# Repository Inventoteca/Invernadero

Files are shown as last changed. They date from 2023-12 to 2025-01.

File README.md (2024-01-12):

# Invernadero
Maqueta de invernadero automatizado.  

Hardware:  
- Módulo ESP32
- Pantalla LCD con controlador ILI9341
- Panel touch resistivo con controlador XPT2046
- Ventiladores 91mm x 91mm 12V
- Puente H DRV8833
- Sensor de temperatura y humedad DHT22
- Bomba de agua peristáltica
- Módulo de 2 relevadores de 5V
- Atomizador de agua piezoeléctrico
- Sensor de humedad de suelo HW-080
- Iluminación con LEDs RGB 12V
- Fuente de alimentación de 12V

En la carpeta "codigo" están los programas escritos en el IDE de Arduino.  
En la carpeta "diagramas" están los diagramas de conexiones creados con Fritzing.  
En la carpeta "dibujo" hay bocetos de la interfaz gráfica.  

Los programas utilizan diversas librerías para cada sensor y actuador.  

Cambiar configuración para que los warnings no sean tratados como errores  
https://forum.arduino.cc/t/esp32-unused-variable-compile-error/1039022/15  

## Pantalla
2.4 pulgadas, resolución 320x240, interfaz SPI, controlador ILI9341.  
http://www.lcdwiki.com/2.4inch_SPI_Module_ILI9341_SKU:MSP2402  

Librería **TFT_eSPI**.
Permite mostrar gráficos de diferentes tipos y también implementa la lectura del panel touch.  
https://github.com/Bodmer/TFT_eSPI  
(tutorial 1: https://electropeak.com/learn/interfacing-2-8-inch-tft-lcd-touch-screen-with-esp32)  
No tine documentación oficial, pero esta sirve  
https://github.com/Ambercroft/TFT_eSPI/wiki  

Se puede usar junto a la librería **tft_eWidget** que define algunos 
elementos para interfaces gráficas, pero no son muy bonitos  
https://github.com/Bodmer/TFT_eWidget  

Librería que se probó anteriormente **Adafruit_ILI9341**  
https://github.com/adafruit/Adafruit_ILI9341  
Esa libreria depende de **Adafruit_GFX** que permite dibujar primitivas gráficas y texto  
https://learn.adafruit.com/adafruit-gfx-graphics-library/graphics-primitives  
Utiliza el hardware SPI. También se puede usar software SPI y elegir los pines, pero la comunicación resulta más lenta.  

## Touch
La pantalla tiene integrado un panel touch resistivo con controlador XPT2046.  

La librería **tft_eSPI** incluye funciones para usar el panel touch.  

Otra librería **XPT2046_Touchscreen**  
https://github.com/PaulStoffregen/XPT2046_Touchscreen  
Esta librería devuelve valores de coordenadas de 0 a 4096 (en en teoría).
No está calibrada a la resolución de la pantalla.
Para convertir las lecturas a coordenadas de la pantalla, se puede usar la función map().  
Usa hardware SPI, el mismo que la pantalla, de esa forma se reutilizan 3 pines del ESP32 (MISO, MOSI, CLK).  
(tutorial 1: https://bytesnbits.co.uk/spi-lcd-setup-arduino/ juego de bloques, cómo se descarga el código?)  
(ejemplo donde se configuran los pines SPI https://www.esp32.com/viewtopic.php?t=3746 
https://gist.github.com/CelliesProjects/99a56121e7c8a7cb00d5b46270e74b75)  
En esta discusión sugieren comprobar el valor de presión para no 
detectar falsos clics si se usa la librería **XPT2046_Touchscreen**  
https://forum.arduino.cc/t/problem-with-il9341-and-xpt2046-phantom-touch/688062  

Este es un fork de la librería aterior, que agrega código para calibración. No se ha probado.  
https://github.com/ardnew/XPT2046_Calibrated  

La librería **URTouch** funcionó correctaente con Arduino Mega, pero no es compatible con ESP32  
http://www.rinkydinkelectronics.com/library.php?id=92  

## Interfaz gráfica
La interfaz gráfica (GUI) se puede crear con diferentes librerías a través de código o de un editor gráfico.  

Una librería es **GUIslice** que tiene un editor gráfico **Gluislice Builder**, 
pero es un poco difícil de usar y los elementos no son bonitos.  

**LVGL** parece una mejor opción, pero aprender a usarla llevará tiempo  
https://daumemo.com/lcd-gui-with-lvgl-with-esp-32-diy-generator-part-15/  

**ESPHome** parece interesante, pero también llevará tiempo aprender a usarla  
https://esphome.io  

Se puede usar **displayio** con **CircuitPyhon**, pero implica volver a programar todo  
https://learn.adafruit.com/circuitpython-display-support-using-displayio  

Colo picker 565  
https://rgbcolorpicker.com/565  

Varios iconos se pueden obtener de estas páginas  
https://klarsys.github.io/angular-material-icons/  
https://fontawesome.com/v4/icons/  
https://github.com/Paul-Reed/weather-icons-lite/blob/master/css_mappings.md  
https://fonts.google.com/icons  

## Ventiladores
Los ventiladores se conectan a un módulo DRV8833 (puente H) y se controlan 
con 2 pines que envían señales PWM para poder regular la velocidad.  
Cada ventilador puede ser controlado con 2 pines, pero solo se usará 1 pin, ya que no es necesario invertir la dirección de giro.  
https://forum.arduino.cc/t/troubleshooting-voltage-drop-to-motors/1135652  
https://circuitdigest.com/microcontroller-projects/interface-drv8833-dual-motor-driver-module-with-arduino  

## Bomba de agua
Se activa con un relevador que es controlado por 1 pin digital.
Se usa un relevador porque no se necesita regular la velocidad.  

## Atomizador
Usa un elemento piezoeléctrico que vibra y expulsa el agua en forma de gotas muy pequeñas. 
No se puede usar pwm directo del microcontrolador al piezoeléctrico porque funciona con voltaje alto.
Se puede conectar un relevador o solo optoacoplador al botón que activa el funcionamiento.  

## Sensor de temperatura y humedad
Sensor DHT22. Solo usa 1 pin de comunicación.  
Librería **DHT sensor library** by Adafruit.  

## Sensor de humedad de suelo
Tiene dos salidas: una digital y una analógica
Dependiendo de la lectura obtenida, se activa o desactiva la bomba de agua.  
Se usará la salida analógica.  
https://www.electronicwings.com/esp32/soil-moisture-sensor-interfacing-with-esp32  

## LEDs
Iluminación con LEDs RGB. Funcionan con 12V. Se controlan con MOSFETs y PWM.  
https://learn.adafruit.com/rgb-led-strips/usage  

## Reloj (opcional)
Módulo RTC para realizar ciclos que dependen de la hora.

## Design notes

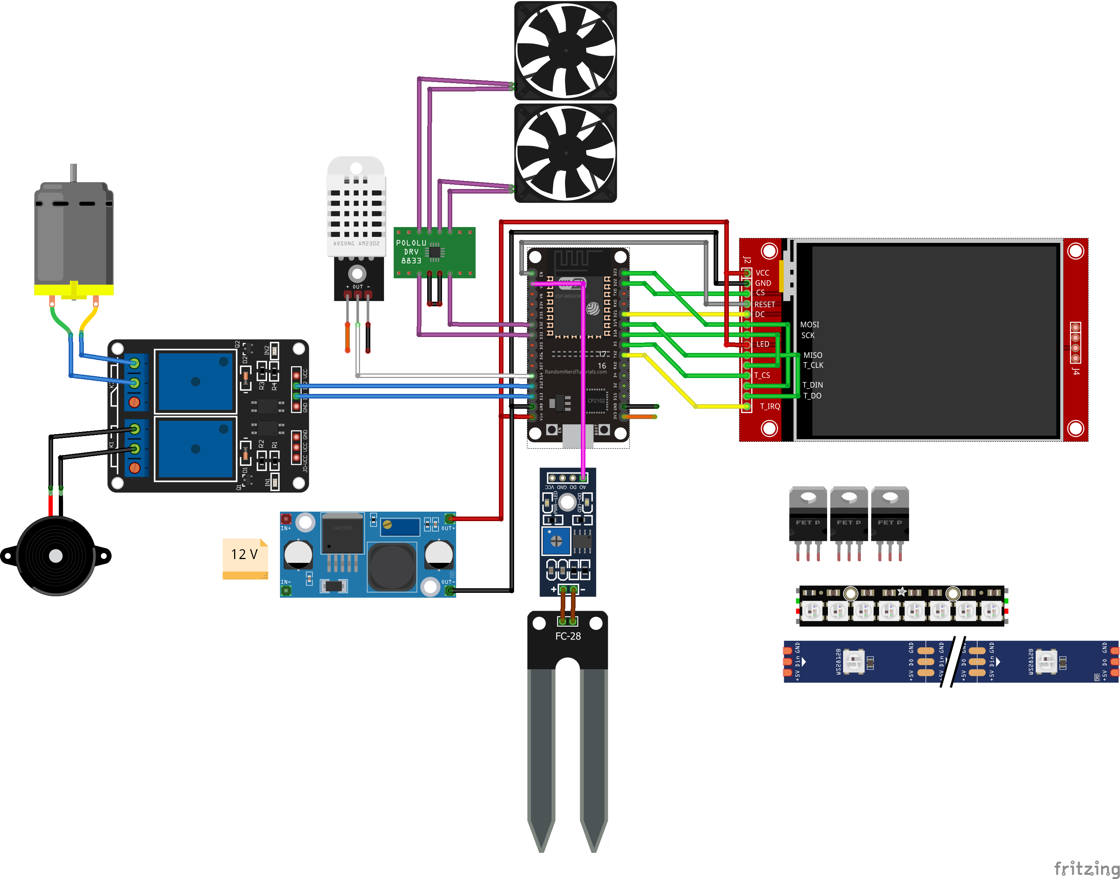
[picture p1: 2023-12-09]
diagrama/diagrama invernadero r2.png

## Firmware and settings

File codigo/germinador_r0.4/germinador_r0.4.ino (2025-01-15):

/*
  GERMINADOR
  Maqueta de invernadero automatizado.
  El código inicial está basado en
  - ejemplo "Keypad_240x320" de la librería TFT_eSPI
  - ejemplo dht22

  En este archivo se encuentra la lógica principal del programa

  Versiones
  0.3 agrega varias pantallas con controles deslizantes
  0.4 cambiar pines y agregar medidor de PH PH
*/

//===================================================================
// Definir pines
#define PIN_SUELOD 35  //sensor de humedad del suelo (lectura digital)
#define PIN_SUELOA 34  //sensor de humedad del suelo (lectura analogica)
#define PIN_PHD 39     //sensor de PH (lectura digital)
#define PIN_PHA 36     //sensor de PH (lectura analogica)
#define PIN_VENT1 32   //ventilador 1 (PWM)
#define PIN_VENT2 33   //ventilador 2 (PMW)
#define PIN_R 12       //LED R (PMW)
#define PIN_G 13       //LED G (PMW)
#define PIN_B 14       //LED B (PMW)
#define PIN_BOMBA 26   //relevador para bomba de agua
#define PIN_SPRAY 25   //relevador para bomba de atomizador/spray
#define PIN_BEEP 17    //buzzer piezoeléctrico

// Los pines para la pantalla y el panel touch se definen en "Setup21_ILI9488.h"

// nuevos pines agregados
//#define PIN_BSPRAY 13  //bomba para el spray
//#define PIN_SSPRAY 39  //36//sensor de agua para el spray
// cada vez que se presiona un botón suena el beep

// sensor de temperatura y humedad
#define PIN_DHT 27
#include "DHT_Async.h"
DHT_Async dht(PIN_DHT, DHT_TYPE_22);
//#include <dhtESP32-rmt.h>
float humedad, temperatura;  //variables para guardar lecturas del sensor
// las lecturas se realizan cada 2 segundos
#define DHT_PERIOD 3000  //4000//periodo de lectura en milisegundos
unsigned long dht_now;   //marca de tiempo en la que se hizo una lectura

// Variables para guardar el estado de los sensores y actuadores
bool suelod;  //guarda un estado alto o bajo
//es alto cuando la resistencia es alta?
int sueloa;  //guarda la lectura analógia (12 bits --> 0 a 4095)
//es el valor de la resistencia de la tierra
//cuando la resistencia es infinita la lectura es 4095
//cuando la resistencia es cero la lectura es 0
//el nivel de humedad como porcentaje se puede calcular así:
//int humedad_suelo = ((4095 - sueloa) * 100) / 4095;
int humedad_suelo = (4095 - sueloa) / 41;  // forma más simple
//se debe cambiar el tipo de variable?
//cuando la humedad baja de un nivel determinado, se enciende la bomba
int lim_humedad_suelo = 50;  //limite de humedad del suelo
//si la humedad baja de ese nivel, se activa la bomba, si se pasa de ese nivel, apaga la bomba
//la lectura de este sensor se realiza con un poco de retardo
#define SH_PERIOD 1000  //sensor humedad periodo
unsigned long sh_now;   //sensor humedad marca temporal

//el estado de los ventiladores se guarda en las siguientes variables
//se usará pwm con resolución de 8 bits (0 a 255)
//pero se usan otras variables que guardan un valor de 0 a 10
//uint8_t vent1 = 0;
//uint8_t vent2 = 0;
float vent1 = 0;
float vent2 = 0;
uint8_t pwm_vent1 = 0;
uint8_t pwm_vent2 = 0;
//el ciclo de trabajo asigna con analogWrite,
//sin embargo la frecuencia del pwm se escucha como zumbido
//para cambiar a una frecuencia no audible se puede usar la librería ledc
//(https://lastminuteengineers.com/esp32-pwm-tutorial/)
//(https://randomnerdtutorials.com/esp32-pwm-arduino-ide/)
//los ventiladores se activan cuando la temperatura ambiente sobrepasa un valor
//uint8_t lim_temperatura = 20; //en grados celcius

int lim_temperatura = 20;  //en grados celcius
//la lectura del sensor es float, se debe usar el mismo tipo de variable?

//para asignar este limite se puede usar una barra deslizadora de 10 a 50 grados
//cuál es el rango ideal?
//los ventiladores pueden encender con una velocidad proporcional a la temperatura
//o pueden encender a una velodiad predeterminada (se encenderán a la máxima velocidad, es más fácil)
//con el control manual se pueden activar los ventiladores de manera independiente,
//pero con el control automático los dos ventiladores se encienden o apagan al mismo tiempo

//los leds usan pwm como los ventiladores (analogWrite)
//es necesario cambiar la resolución o frecuencia de pwm para los leds?
uint8_t pwm_r = 0;
uint8_t pwm_g = 0;
uint8_t pwm_b = 0;
//qué condición hace que los leds enciendan?
//puede ser un temporizador que active la luz por periodos
//por ahora solo controlarán de forma manual
//estos son los valores por defatul al encender cuando el control sea atuomático
uint8_t def_r = 255;
uint8_t def_g = 255;
uint8_t def_b = 255;
//
float val_r = 0;
float val_g = 0;
float val_b = 0;

//la bomba de agua se activa con un relevador. Tiene lógica invertida:
//cuando el pin está en HIGH, la bomba se apaga
//cuando el pin está en LOW, la bomba se enciende
bool bomba = false;  //estado de la boma, el pin se escribirá invertido

//el nebulizador/atomizador/spray también se activa con un relevador
bool spray = false;  //estado del spray
//se necesitaba un pulso, pero ya no
//pero necesita un pulso (flanco descendente) para activarse y otro pulso para desactivarse
//qué duración debe tener ese pulso?
//#define T_PULSO_SPRAY 30  //milisegundos
//el relevador se activa un momento y luego se desactiva

#define T_PULSO_BEEP 30  //milisegundos, duracion minima del beep

int lim_humedad = 60;  //si baja de este valor, se activa el nebulizador
//float lim_humedad = 60; //usar float?

//puede existir un control para seleccionar funcionamiento manual o automático
//por ahora se cambiará a manual si se cambian los valores de los actuadores
//y regresará a automático si se cambian los valores de los límites
bool vent_auto = true;   //ventilador automático (se activa con la temperatura)
bool spray_auto = true;  //nebulizador/spray automático (se activa con la humedad)
bool bomba_auto = true;  //bamba automática (se activa con la humedad del suelo)
/*
  ¿Qué pasa si el usuario utiliza el control manual?
  Lo más fácil es sobre-escribir el valor al instante
  y cuando vuelve a leer el sensor retoma el valor por default.
  La segunda opción es que cuando el usuario usa el control manual
  se activa un temporizador que mantiene los valores por un minuto
  y luego regresa a su valor por default
  También se puede reactivar el control automático si se reasigna el valor límite
*/

// Código para el display
#include "display.h"

// Código para el access point y página web
#include "server.h"

//------------------------------------------------------------------------------------------
void setup() {
  // configurar entradas y salidas
  pinMode(PIN_SUELOD, INPUT);
  pinMode(PIN_SUELOA, INPUT);
  pinMode(PIN_VENT1, OUTPUT);
  pinMode(PIN_VENT2, OUTPUT);
  pinMode(PIN_R, OUTPUT);
  pinMode(PIN_G, OUTPUT);
  pinMode(PIN_B, OUTPUT);
  pinMode(PIN_BOMBA, OUTPUT);
  pinMode(PIN_SPRAY, OUTPUT);  //controlar spray
  //pinMode(PIN_BSPRAY, OUTPUT);  //bomba spray
  //pinMode(PIN_SSPRAY, INPUT);   //sensor spray
  pinMode(PIN_BEEP, OUTPUT);  //buzzer piezoeléctrico
  //
  analogRead(PIN_SUELOA);  //descartar primera lectura
  analogRead(PIN_PHA);     //descartar primera lectura
  analogWrite(PIN_VENT1, 0);
  analogWrite(PIN_VENT2, 0);
  analogWrite(PIN_R, 0);  //si el pin es DAC no saca PWM?
  analogWrite(PIN_G, 0);
  analogWrite(PIN_B, 0);
  digitalWrite(PIN_BOMBA, HIGH);  //relevador apagado en HIGH
  //digitalWrite(PIN_BSPRAY, HIGH);  //relevador apagado en HIGH
  digitalWrite(PIN_SPRAY, HIGH);  //relevador apagado en HIGH
  digitalWrite(PIN_BEEP, HIGH);
  digitalWrite(PIN_BEEP, LOW);
  //
  //dht.begin();
  //uint8_t dht_error = read_dht(temperatura, humedad, PIN_DHT, DHT22); //descartar primera lectura
  dht.measure(&temperatura, &humedad);  //descartar primera lectura
  dht.measure(&temperatura, &humedad);
  dht_now = millis();  //guardar marca temporal
  digitalWrite(PIN_BEEP, LOW);

  // Use serial port
  Serial.begin(115200);
  Serial.print("\nGERMINADOR\n");
  digitalWrite(PIN_BEEP, LOW);

  // Initialise the TFT screen
  tft.init();
  tft.setRotation(1);  //3 // Set the rotation before we calibrate
  touch_calibrate();   // Calibrate and retrieve the scaling factors
  //tft.fillScreen(TFT_BLACK); // Clear the screen
  digitalWrite(PIN_BEEP, LOW);

  // Mensaje de bienvenida
  tft.fillScreen(FONDO);
  tft.setTextFont(4);
  tft.setTextSize(1);
  tft.setTextColor(TFT_WHITE);
  tft.setTextDatum(TC_DATUM);  //top-centre
  tft.drawString("GERMINADOR PARA ZONAS URBANAS", 160, 80);
  tft.drawString("CONTROLADO MEDIANTE TECNOLOGIA IoT", 160, 110);

  // Iniciar server
  serverSetup();
  delay(2000);  //esperar para que se vea el mensaje de bienvenida

  //Inicializar controles de todas las pantallas/páginas
  setupUI0();  //principal
  setupUI1();  //temperatura
  setupUI2();  //humedad
  setupUI3();  //humedad suelo
  setupUI4();  //ventiladores
  setupUI5();  //color
  setupUI6();  //conectar
  drawUI0();   //Dibujar interfaz principal
  //drawUI1();
  //while (true) {}
}

//------------------------------------------------------------------------------------------
void loop(void) {
  // Leer sensor dht de manera periódica =================================
  if ((unsigned long)(millis() - dht_now) > DHT_PERIOD) {
    dht_now = millis();
    dht.measure(&temperatura, &humedad);

    //imprimir en consola
    /*
    Serial.print("T: ");
    Serial.print(temperatura, 1);
    Serial.print("  H: ");
    Serial.print(humedad, 1);
    Serial.println("%");
    */

    //actualizar pantalla principal
    if (pantalla == 0) {
      tft.setTextFont(4);
      tft.setTextSize(1);
      tft.setTextColor(TFT_WHITE, TFT_BLACK);
      String t = String(temperatura, 0) + " `C  ";
      String h = String(humedad, 0) + "%   ";
      tft.drawString(t, btx0[0], bty0[0]);
      tft.drawString(h, btx0[1], bty0[1]);
    }

    //si está activado el control automático del ventilador
    if (vent_auto) {
      //si la temperatura sobrepasa el límite
      if (temperatura > lim_temperatura) {
        vent1 = 10;  //encender a la máxima velocidad
        vent2 = 10;
        analogWrite(PIN_VENT1, vent1 * 25.5);
        analogWrite(PIN_VENT2, vent2 * 25.5);
        Serial.println("Vent ON (auto)");
      }
      //si la temperatura está debajo del límite
      else if (temperatura < lim_temperatura) {
        vent1 = 0;  //apagar ventiladores
        vent2 = 0;
        analogWrite(PIN_VENT1, vent1 * 25.5);
        analogWrite(PIN_VENT2, vent2 * 25.5);
        Serial.println("Vent OFF (auto)");
      }
    }  //fin if vent_auto

    //si está activado el control automático del nebulizador/spray
    if (spray_auto) {
      //si la humedad es más baja que el límite
      if (humedad < lim_humedad) {
        //encender el spray solo si está apagado
        if (spray == false) {
          digitalWrite(PIN_SPRAY, LOW);  //recuerda, el relevador se activa en bajo
          //delay(T_PULSO_SPRAY);           //tiempo que tarda el pulso
          //digitalWrite(PIN_SPRAY, LOW);   //desactivar relevador
          spray = true;                   //guardar estado actual
          Serial.println("Spray ON (auto)");
          if (pantalla == 0) tft.drawXBitmap(bix0[5], biy0[5], bi0[5], 32, 32, TFT_CYAN);
        }
      }
      // si la humedad está arriba del límite
      else if (humedad > lim_humedad) {
        //apagar el nebulizador spray, solo si está encendido
        if (spray == true) {
          digitalWrite(PIN_SPRAY, HIGH);  //recuerda, el relevador se activa en bajo
          //delay(T_PULSO_SPRAY);           //tiempo que tarda el pulso
          //digitalWrite(PIN_SPRAY, LOW);   //desactivar relevador
          spray = false;                  //guardar estado actual
          Serial.println("Spray OFF (auto)");
          if (pantalla == 0) tft.drawXBitmap(bix0[5], biy0[5], bi0[5], 32, 32, 0);
        }
      }
    }  //fin if spray_auto
  }    //fin DHT_PERIOD

  // El sensor de humedad de suelo se lee más seguido ===============================
  // XXXXXXXXXXXXX También se lee el sensor de agua dentro para el spray XXXXXXXXXX
  if ((unsigned long)(millis() - sh_now) > SH_PERIOD) {
    sh_now = millis();
    suelod = digitalRead(PIN_SUELOD);      //lectura digital
    sueloa = analogRead(PIN_SUELOA);       //lectura analógica
    humedad_suelo = (4095 - sueloa) / 41;  //calcular porcentaje de humedad
    //
    //sensor de agua para el spray
    // 0 significa nivel alto, 1 significa nivel bajo
    // activar o desactivar la bomba
    //digitalWrite(PIN_BSPRAY, !digitalRead(PIN_SSPRAY));
    /*
    Serial.print("HS: ");
    Serial.print(humedad_suelo);
    Serial.println("%");
    */

    // Actualizar pantalla 0 (principal)
    if (pantalla == 0) {
      tft.setTextFont(4);
      tft.setTextSize(1);
      tft.setTextColor(TFT_WHITE, TFT_BLACK);
      String hs = String(humedad_suelo) + "%   ";
      tft.drawString(hs, btx0[2], bty0[2]);
    }

    //si el control automático de la bomba está activado
    if (bomba_auto) {
      //si la humedad del suelo está debajo del límite
      if (humedad_suelo < lim_humedad_suelo) {
        digitalWrite(PIN_BOMBA, LOW);  //encendido en nivel bajo
        bomba = true;                  //guardar estado actual
        Serial.println("Bomba ON (auto)");
        //dibujar icono
        if (pantalla == 0) tft.drawXBitmap(bix0[6], biy0[6], bi0[6], 32, 32, TFT_CYAN);
      }
      //en cambio, si la humedad del suelo está arriba del límite
      if (humedad_suelo > lim_humedad_suelo) {
        digitalWrite(PIN_BOMBA, HIGH);  //apagado en nivel alto
        bomba = false;                  //guardar estado actual
        Serial.println("Bomba OFF (auto)");
        //dibujar icono
        if (pantalla == 0) tft.drawXBitmap(bix0[6], biy0[6], bi0[6], 32, 32, 0);
      }
    }
  }

  //Detectar clics en la pantalla ============================================
  if ((unsigned long)(millis() - touch_now) > TOUCH_PERIOD) {
    touch_now = millis();

    //realizar acciones de la pantalla conrrespondiente
    switch (pantalla) {
      case 0:
        loopUI0();
        break;
      case 1:
        loopUI1();
        break;
      case 2:
        loopUI2();
        break;
      case 3:
        loopUI3();
        break;
      case 4:
        loopUI4();
        break;
      case 5:
        loopUI5();
        break;
      case 6:
        loopUI6();
        break;
    }
  }  //fin TOUCH_PERIOD

  // Actualizar server ===================================================
  serverLoop();

}  //fin loop()
//Fin del programa

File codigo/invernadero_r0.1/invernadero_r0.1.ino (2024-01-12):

/*
  INVERNADERO
  Maqueta de invernadero automatizado.
  El código inicial está basado en el ejemplo "Keypad_240x320" de la librería TFT_eSPI.
  Se utiliza la clase "button".
*/

// The SPIFFS (FLASH filing system) is used
// to hold touch screen calibration data
#include "FS.h"

// Iconos
#include "icons/th32.h" //thermometer
#include "icons/drop32.h" //water drop
#include "icons/grass32.h" //grass
#include "icons/fan32.h" //fan
#include "icons/lamp32.h" //lamp
#include "icons/sprink32.h" //sprinkler
#include "icons/pump32.h" //water pump

// Colores
#define FONDO 0x1084
#define PANEL 0x526d
#define GRIS70 0x4a69
#define ICON TFT_CYAN

#include <SPI.h>
#include <TFT_eSPI.h>      // Hardware-specific library
TFT_eSPI tft = TFT_eSPI(); // objeto para manejar la pantalla

// This is the file name used to store the calibration data
// You can change this to create new calibration files.
// The SPIFFS file name must start with "/".
#define CALIBRATION_FILE "/TouchCalData1"

// Set REPEAT_CAL to true instead of false to run calibration
// again, otherwise it will only be done once.
// Repeat calibration if you change the screen rotation.
#define REPEAT_CAL true
// en lugar de usar este define se usará un botón para iniciar la calibración

// Botones de la pantalla principal
TFT_eSPI_Button b[8]; //objetos botón
const int bx[8] = { 20,  20,  20, 180, 250, 180, 250, 180}; //x top-left corner
const int by[8] = { 20,  90, 160,  20,  20,  90,  90, 160}; //y top-left corner
const int bw[8] = {140, 140, 140,  60,  60,  60,  60, 130}; //wdith
const int bh[8] = { 60,  60,  60,  60,  60,  60,  60,  60}; //height
char* bl[8] = {"", "", "", "", "", "", "", "CONECTAR"}; //labels
const uint16_t bc[8] {0, 0, 0, PANEL, PANEL, PANEL, PANEL, PANEL}; //colors
const uint8_t* bi[8] = { //icons
  th32_bits, drop32_bits, grass32_bits,
  fan32_bits, lamp32_bits, sprink32_bits, pump32_bits, 0
};
const int bix[8] = { //icon x top-left corner
  40 - 16, 40 - 16, 40 - 16, 210 - 16, 280 - 16, 210 - 16, 280 - 16, 0
};
const int biy[8] = { //icon y top-left corner
  50 - 16, 120 - 16, 190 - 16, 50 - 16, 50 - 16, 120 - 16, 120 - 16, 0
};

//===================================================================
// Definir pines
// Los pines para la pantalla y el panel touch se definen en "Setup42_ILI9341_ESP32.h"
#define PIN_SUELOD 34 //sensor de humedad del suelo (lectura digital)
#define PIN_SUELOA 35 //sensor de humedad del suelo (lectura analogica)
#define PIN_VENT1 32 //ventilador 1 (usa PWM)
#define PIN_VENT2 33 //ventilador 2 (usa PMW)
#define PIN_R 26 //LED R (usa PMW)
#define PIN_G 25 //LED G (usa PMW)
#define PIN_B 27 //LED B (usa PMW)
#define PIN_BOMBA 14 //bomba de agua
#define PIN_SPRAY 13 //atomizador/spray

// sensor de temperatura y humedad
#include "DHT.h"
#define PIN_DHT 15
DHT dht(PIN_DHT, DHT22); //objeto para leer el sensor DHT22

//------------------------------------------------------------------------------------------

void setup() {
  // configurar entradas y salidas
  pinMode(PIN_SUELOD, INPUT);
  pinMode(PIN_SUELOA, INPUT);
  pinMode(PIN_VENT1, OUTPUT);
  pinMode(PIN_VENT2, OUTPUT);
  pinMode(PIN_R, OUTPUT);
  pinMode(PIN_G, OUTPUT);
  pinMode(PIN_B, OUTPUT);
  pinMode(PIN_BOMBA, OUTPUT);
  pinMode(PIN_SPRAY, OUTPUT);
  //
  analogRead(PIN_SUELOA); //descartar primera lectura
  analogWrite(PIN_VENT1, 0);
  analogWrite(PIN_VENT2, 0);
  analogWrite(PIN_R, 0); //si el pin es DAC no saca PWM?
  analogWrite(PIN_G, 0);
  analogWrite(PIN_B, 0);
  digitalWrite(PIN_BOMBA, HIGH); //relevador apagado en HIGH
  digitalWrite(PIN_SPRAY, HIGH); //relevador apagado en HIGH
  //
  dht.begin();

  // Use serial port
  Serial.begin(115200);

  // Initialise the TFT screen
  tft.init();
  tft.setRotation(3);//3 // Set the rotation before we calibrate
  touch_calibrate(); // Calibrate and retrieve the scaling factors
  //tft.fillScreen(TFT_BLACK); // Clear the screen

  // Inicializar botones
  for (uint8_t i = 0; i < 8; i++) {
    b[i].initButtonUL(&tft, bx[i], by[i], bw[i], bh[i], bc[i], bc[i], TFT_WHITE, bl[i], 1);
  }
  drawUI(); //Dibujar interfaz
}

//------------------------------------------------------------------------------------------

void loop(void) {
  /*
    // Reading temperature or humidity takes about 250 milliseconds!
    // Sensor readings may also be up to 2 seconds 'old' (its a very slow sensor)
    float h = dht.readHumidity();
    // Read temperature as Celsius (the default)
    float t = dht.readTemperature();
    Serial.print(h);
    Serial.println(t);
  */
  // Pressed will be set true is there is a valid touch on the screen
  uint16_t tx = 0, ty = 0; // To store the touch coordinates
  bool pressed = tft.getTouch(&tx, &ty, 0); //using threshold

  //if (pressed) { //si la pantalla es tocada
  for (uint8_t i = 0; i < 8; i++) { //revisar los botones
    if (pressed and b[i].contains(tx, ty)) { //si el botón es tocado
      b[i].press(true); //marcar como presionado
    } else {
      b[i].press(false); //en caso contrario, marcar como no presionado
    }

    // Si el botón se acaba de presionar, dibujarlo presionado
    if (b[i].justPressed()) {
      b[i].drawButton(true); //inverted/pressed
    }

    // Si el botón se acaba de soltar, realizar una acción
    if (b[i].justReleased()) {
      //acción
      //drawUI();
      b[i].drawButton(false); //dibujar normal
      if (i != 7) {
        tft.drawXBitmap(bix[i], biy[i], bi[i], 32, 32, ICON);
      }
      switch (i) {
        case 0: //temperatura
          break;
        case 1: //humedad del aire
          break;
        case 2: //humedad del suelo
          break;
        case 3: //ventilador
          break;
        case 4: //LEDs
          break;
        case 5: //spray/atomizador
          break;
        case 6: //bomba de agua
          break;
        case 7: //conectar
          break;
      }
    }
  }//fin for
  //}//fin if pressed

  /*
    // Update the number display field
    tft.setTextDatum(TL_DATUM);        // Use top left corner as text coord datum
    tft.setFreeFont(&FreeSans18pt7b);  // Choose a nicefont that fits box
    tft.setTextColor(DISP_TCOLOR);     // Set the font colour

    // Draw the string, the value returned is the width in pixels
    int xwidth = tft.drawString(numberBuffer, DISP_X + 4, DISP_Y + 12);

    // Now cover up the rest of the line up by drawing a black rectangle.  No flicker this way
    // but it will not work with italic or oblique fonts due to character overlap.
    tft.fillRect(DISP_X + 4 + xwidth, DISP_Y + 1, DISP_W - xwidth - 5, DISP_H - 2, TFT_BLACK);
  */

  delay(50); // UI debouncing
} //fin loop()

// Mi función para dibujar botones
void drawButton() {
  // por ahora no se usa
}
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

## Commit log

2023-12-02 subir programas de prueba
2023-12-02 subir diagrama fritzing y partes descargadas
    [ESP32_Boards.fzz, diagrama invernadero r1.fzz, esp32.fzz]
2023-12-03 cambiar pin dc
2023-12-03 diagrama con pines nuevos
    [diagrama invernadero r2.fzz]
2023-12-04 secciones para cada módulo en el readme
2023-12-08 subir diseño de la interfaz gráfica
2023-12-08 agregar enlaces de tutoriales
2023-12-08 enlaces para iconos
2023-12-08 crear programa que combina todo
2023-12-08 mover pines de ventilador y sensor de suelo
    [diagrama invernadero r2.fzz]
2023-12-10 subir programa de interfaz html
2023-12-10 actualizar pines
    [diagrama invernadero r2.fzz]
2023-12-11 cambiar nombre de red y probar otros pines
2023-12-11 subir archivos de configuración
2024-01-10 arreglar lógica de touch
    [invernadero_r0.1.ino]
2024-01-12 copiar código a archivo html para estudiarlo
2024-01-12 mover archivos de fritzing descargados
    [ESP32_Boards.fzz, esp32.fzz]
2024-01-12 actualizar lista de hardware
2024-01-12 dibujo de segunda pantalla
2024-01-13 dibujo de otras pantallas
2024-01-13 probar cambio de pantalla
2024-01-14 probar colores de sliders
2024-01-14 hacer funcionar pantalla temperatura
2024-01-15 ajustar pos de texto en pantalla color
2024-01-15 corregir varios bugs y agregar prueba de server
    [invernadero_r0.3.ino]
2024-01-16 corregir función para dibujar bitmaps escalados
2024-01-18 quitar flicker en control leds
2024-01-18 actualizar pagina web con deslizadores para limites
2024-01-19 cambiar nombres de dispositivos
2024-01-19 comentar varias líneas Serial.print
2024-01-21 agregar segunda bomba y buzzer
    [diagrama invernadero r2.fzz]
